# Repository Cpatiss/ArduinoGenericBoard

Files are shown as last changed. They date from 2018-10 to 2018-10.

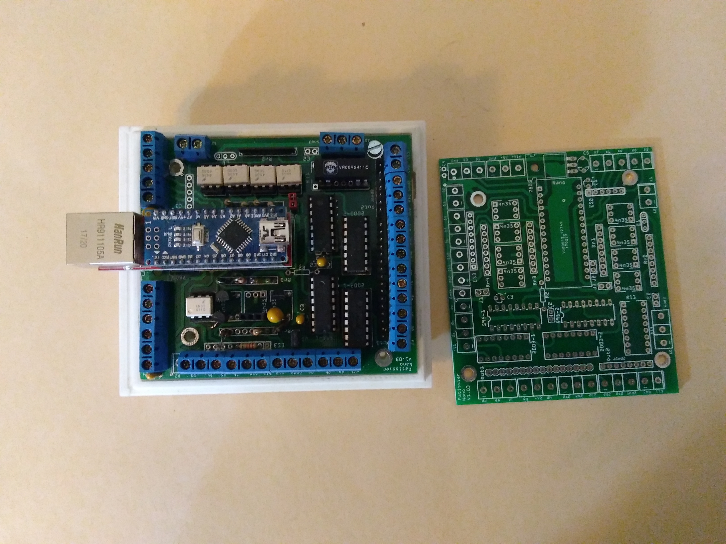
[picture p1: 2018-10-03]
IMG_20181002_145330114.jpg

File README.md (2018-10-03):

# ArduinoGenericBoard
Generic board for Arduino Nano and ENC28J60 Shield (optional)

PCB layout, fritzing included, gerber files in zip also included for Arduino Nano with printer 3D Case
Case is able to set on DIN rail
+ With optional shield RJ45 ENC28J60 - drive by UIPEthernet.h via SPI 10-11-12-13 pins. 
+ With 2 shift registers (SN74HC595) and 2 drivers (ULN 2003) witch provide 16 extra OUTs (14 drived by ULN provide high current outputs, one connected to reed relay) (only use D7, D8, D9 for synchrone serial)
+ With 7 optocouplers 4N25 or equ. (6 for input ,1 for output).All pul-up resistors could be individual or resistor type B array
+ With Voltage regulator (7805).It can be added a cooling radiator (on the bottom side if shield ENC28J60 plugs as picture show)

All the input/output are on screw terminal (protected by case) arround the case and both (almost) on a 2.54 SIL connector.

A sample of arduino program (to be continued) is also included.

Boitier (sur rail DIN) pour une carte arduino Nano (Tracé de circuit Frtizing inclus, fichiers  des gerber en zip aussi) incluant :
+ La place pour une carte ENC28J60 shield internet pour Nano (utilisant la liaison SPI via les E/S D10,11,12 et 13).
Cette carte est optionnelle ces E/S sont sinon disponibles sur les borniers.
+ 2 registres à décalage (SN74HC595) accolés à deux drivers (ULN2003) procurant 14 sorties fort courant plus une connectée à un relais reed.
Ces sorties n'utilisent que 3 E/S de l'arduino (D7,8 et9).
+ 6 Entrées optocouplées et une sortie optocouplée via des 4N25 (ou équivalents). Toutes les résistances de tirages peuvent être individuelles ou des réseaux de resistances de type B.
+ Un régulateur de tension (7805) avec radiateur (celui-ci doit être monté coté soudure en cas d'utilisation du shield internet , comme sur les photos jointes).

Toutes les entrées/ sorties sont disponibles sur des bornes à vis (d'accès protégé par le boitier) disposées tout autour de celui-ci et pour la plupart disponibles sur des connecteurs SIL au pas de 2.54.

Un petit exemple de programme arduino (à compléter) est également disponible.

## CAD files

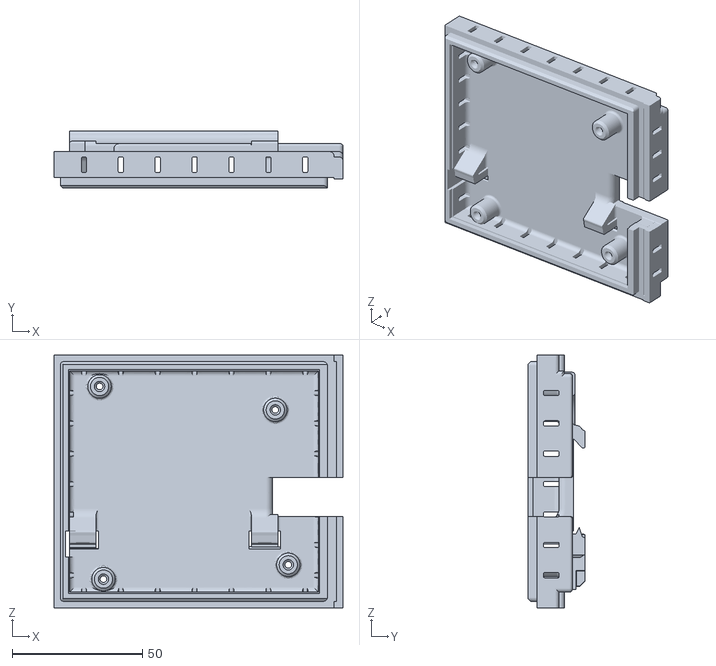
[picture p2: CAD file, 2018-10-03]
Down din V30.stl
111.0 x 22.0 x 97.0

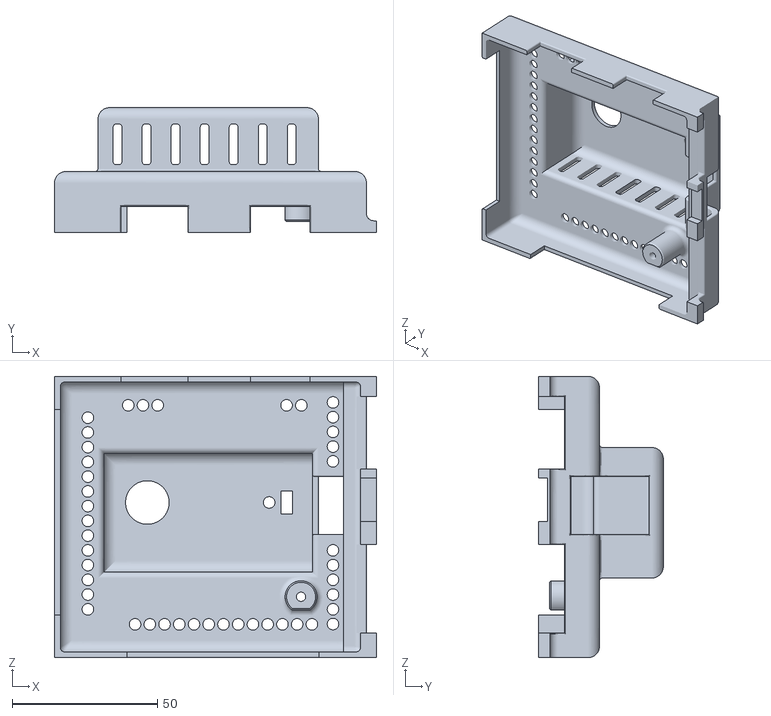
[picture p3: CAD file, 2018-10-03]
Top V22.stl
111.0 x 43.0 x 97.0

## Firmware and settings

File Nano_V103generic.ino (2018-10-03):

#define withinternet "yes" // commenté ou décommenté pour utilisation du shield ENC28J60/ comment or uncomment for use or not ENC28J60 Shield
#ifdef withinternet 
	#include <UIPEthernet.h>
	#include <SPI.h>
#else
	//#include <UIPEthernet.h> // certains compilateur reclame cette ligne / somme compiltor nedd this line
#endif

#define indebugmode "yes" // mode débuguage / mode debug

#define uchar unsigned char // pour faciliter code / for easier code
#define uint  unsigned int // pour faciliter code / for easier code

/* base sur le circuit imprime Nano V1.03 fritzing avec un arduino nano 
based on nano v1.03 Board see fritzing project with arduino nano chip  */

/* utilisation de deux '74HC595' (registre a decalage 8 bits) montes en serie pour generer 16 sorties (14 driver par dalington ULN2003) avec 3 pins seulement
	to drive 16 outputs (14 drive through darlington, ULN2003) via two 74HC595 (shift register) with only 3 pins */
#define pin_Ser  9   //pin 14 (ser) on the 75HC595 n° 1 data serial
#define pin_RClk  8  //pin 12 on the 75HC595 (RCLK) = data set
#define pin_SrClk  7 //pin 11 on the 75HC595 (SRCLK) = Data shift

uchar FirstOutputValue = '\0'; // valeurs des 8 premieres sorties (74hc595 n°1) / value of the first 74hc595 8 first outputs
uchar SecondOutputValue = '\0'; // valeurs des 8 dernieres sorties (74hc595 n°2) / value of the second 74hc595 8 lest outputs values

#ifdef withinternet 
  #define pin_I13_Sck 13 // pin D13 entree  optocouple (sck) vers moduel ethernet / D13 input sck for shield internet
  #define pin_I12_Miso 12 // pin D12 en entree optocouple  (miso) vers module ethernet / D12 input miso for shield internet
  #define pin_O11_Mosi 11 // pin D11 en sortie optocouple (mosi) vers module ethernet / D11 output mosi for shield internet
  #define pin_O10_Css 10 // pin D10 en sortie module ethernet (css) vers module ethernet / D13 output css for shield internet
#endif
#define pin_I06 6 // pin D6 en entree optocouple (rx manchester filaire ou rf)
#define pin_O05 5 // pin D5 en Sorties directe (out RF ou filaire manchester)
#define pin_IO04 4 // pin D4 en E/S directe
#define pin_IO03 3 // pin D3 en E/S directe
#define pin_IO02 2 // pin D2 en E/S directe

#define pin_IO01 1 // pin D1 tx/rx serial use with usb/serial link not use on board nano v1.03
#define pin_IO00 0 // pin D0 tx/rx serial use with usb/serial link not use on board nano V1.03

#define pin_IA0 A0 // pin A0 en entree optocouple (...)
#define pin_IA1 A1 // pin A1 en entree optocouple (...)
#define pin_IA2 A2 // pin A2 en entree optocouple (...)
#define pin_IOA3 A3 // pin A3 en entree sortie directe (...)
#define pin_IOA4 A4 // pin A4 en entree sortie directe (...)
#define pin_IOA5 A5 // pin A5 en sortie directe (...)
#define pin_IOA6 A6 // pin A6 en entree sortie directe (...)
#define pin_IOA7 A7 // pin A7 en entree sortie directe (...)

//def & init for machester
#define BUFFER_SIZE 4 // 3*8 bits = 24 bits (ou 32 bits passer alors  4)  habituel de manchester code chacon (voir pour diagral) par exemple, changer selon besoin
// when use manchester number of bytes used (3 for 24bits long message , 4 for 32 ..) change depend on define bellow
// Modifier aussi le traitement des codes recus dans LOOP // Change also recieve sub in loop function

uint8_t buffer[BUFFER_SIZE + 1];
#ifdef indebugmode
	// int serialNumModule = 0; // numero du module pour les envois serial (/0 ,/1,/2,/3,/4...)
#endif


#ifdef withinternet
	// L'adresse MAC du shield // mac adress of shield
	byte mac[] = { 0x90, 0xA2, 0xDA, 0x0E, 0xA5, 0x7D };
	// L'adresse IP que prendra le shield // fixed ip 
	IPAddress ip(10, 10, 1, 85);

	// Initialise notre serveur / initialize server
	// Ce dernier ecoutera sur le port 80 / server listen on port 80
	EthernetServer serveur(80);

	String url = String("") ; // L'url recu a stocker / to store url received from client
	//char url[100];
	char index = 0; // index indiquant ou l'on est rendu dans la chaine / index of current character of url
#endif


void setup()
{

  // pins 
  #ifdef withinternet 
	  pinMode(pin_I13_Sck, INPUT); // e/s horloge spi web / input/out clock shield web
	  pinMode(pin_I12_Miso , INPUT); // entrée miso spi web / input miso shield web
  #else
    pinMode(pin_I13_Sck, INPUT); // entrée optocouplée / optocoupled input
    pinMode(pin_I12_Miso , INPUT); // entrée optocouplée / optocoupled input
  #endif
	pinMode(pin_I06, INPUT); // input rx (rf ou filaire) manchester
	pinMode(pin_IA0, INPUT);
	pinMode(pin_IA1, INPUT);
	pinMode(pin_IA2, INPUT);
	
  #ifdef withinternet 
	  pinMode(pin_O11_Mosi, OUTPUT); // sortie mosi spi web  / out mosi shield web
	  pinMode(pin_O10_Css, INPUT);// E/sortie chip select shield web / out Css shield web
  #else
    pinMode(pin_O11_Mosi, OUTPUT); // sortie optocouplé  / optocoupled out 
    pinMode(pin_O10_Css, INPUT);// Entrée optocouplée / optocoupled input
  #endif
	pinMode(pin_O05, OUTPUT); // E/S directe / in/out direct
  
	pinMode(pin_Ser, OUTPUT); // ligne data série synchrone registre à décalage / data serial syncrone for shift registers
  pinMode(pin_RClk, OUTPUT); // ligne stockage série synchrone registre à décalage / lacth serial syncrone for shift registers
	pinMode(pin_SrClk, OUTPUT); // ligne horloge série synchrone registre à décalage / clock serial syncrone for shift registers
	
	//pinMode(LED_BUILTIN, OUTPUT);// to test

	// init
	SetOutput495(); // initialise a 0 les sorties des registres 74595 / reset all shift register output

#ifdef indebugmode
	Serial.begin(9600);
#endif
	
	char erreur = 0;
#ifdef withinternet
	// On demarre le shield Ethernet SANS adresse ip (donc donnee via DHCP) // try to start ethernet in DHCP
	//erreur = Ethernet.begin(mac); // décommenté pour démarrer en dhcp /uncomment to start in dhcp
  // ip fixe obligatoire pour le système domotic
	//if (erreur == 0) {// décommenté pour démarrer en dhcp /uncomment to start in dhcp
		#ifdef indebugmode
				Serial.println("IP F");
		#endif
		// si une erreur a eu lieu cela signifie que l'attribution DHCP
		// ne fonctionne pas. On initialise donc en forcant une IP
		Ethernet.begin(mac, ip);
	//}// décommenté pour démarrer en dhcp /uncomment to start in dhcp
	#ifdef indebugmode
		Serial.println("I..");
		Serial.println(Ethernet.localIP());
	#endif
	// Donne une seconde au shield pour s'initialiser
	delay(1000);
	// On lance le serveur
	serveur.begin();
	#ifdef indebugmode
		Serial.println("P!");
	#endif
#endif

	

}// fin setup / end setup 

void loop()
{
	/* set here your loop code
   *  poser ici votre code programme
	 */
#ifdef withinternet
	// traite les requetes web / Web server listen
	// Regarde si un client est connecte et attend une reponse/ look if client connected
	EthernetClient client = serveur.available();
	
	if (client) { // Un client est la ? / a client is here ?
		#ifdef indebugmode
			Serial.println("i!");
		#endif
		url = String("                     "); // on remet a zero notre chaine tampon /  reset string
		index = 0;
		while (client.connected()) { // Tant que le client est connecte / while client connected
			if (client.available()) { // A-t-il des choses a dire ? / and client have someting to say
				
				// traitement des infos du client / operate client string
				char carlu = client.read(); //on lit ce qu'il raconte / read string
				if (carlu != '\n') { // On est en fin de chaine ? / end of client string
					// non ! alors on stocke le caractere / no we continue
					#ifdef indebugmode
						Serial.print(carlu);
					#endif
					url[index] = carlu;
					index++;
					if (index > 25){ index = 0; Serial.println(""); }
				}
				else {
					// on a fini de lire ce qui nous interesse / end of client string
					#ifdef indebugmode
						Serial.println("");
					#endif
					// on marque la fin de l'url (caractere de fin de chaine) / set end of string by chr 0
					url[index] = '\0';
					boolean ok = WebValid(client); // essaie d'interpreter la chaine / try to explot string
					if (ok) {
						// tout s'est bien passe = on met a jour les broches / if all is ok operate
           /* poser ici votre code de fin de traitement web 
            *  set here your end web treatment code 
            */
						//ction();
					}
					break;
				}
			}
		}
		// Donne le temps au client de prendre les donnees / left time client to recieve answer
		delay(10);
		// Ferme la connexion avec le client / close client connection
		client.stop();
		#ifdef indebugmode
				Serial.println("o!");
		#endif
	}
#endif

} // fin loop / end loop

#ifdef withinternet
	 boolean WebValid(EthernetClient client) {
		// renvoi true si la chaine est valide, traite les infos de la chaine
		//Serial.print("receive : ");
		//	Serial.print(url);
		int pos = url.indexOf("o="); // si message commence par o= alors met sorties à jour/ if message begin by 'o=' set output as sended
		//Serial.println(pos);
		if (pos > 0) {
			// renvoi ok 
			enteteClientWebJson(client);
			client.println("OK");
			//puis traite message
			Set3FristBuffer(pos);
			if (buffer[1] != 1) {
				// ordre <>1 met les sorties demandés dans le message / order <>1  set output as value sended 
				char tmp[2] = {'0', url[pos + 9]};
        int numModuleCourant = 0;
				numModuleCourant = atoi(tmp);
				// Serial.println(numModuleCourant);
				FirstOutputValue = (FirstOutputValue | 0x7F) & ( numModuleCourant);
				SetOutput495();
			
			}
			else {
				// ordre de modifier les sorties du nano
				if (( buffer[2] & 0x01 )==1) { 
				SecondOutputValue = buffer[2]>>1;
				SetOutput495();
				}
       
			}
			
			return true;
		}
		else // si le message ne commnce pas par 'o=' / if message not begin by 'o='
      // envoi la page Web des statuts des entrées et sorties / send web page with input/output status
			{
				pos = url.indexOf("S=");
				//Serial.println(pos);
				if (pos > 0) {
					Set3FristBuffer(pos);
					// puis message traite
					enteteClientWebJson(client);
					client.print("{\"ST\":");
					// client.print(lastHeaderGroup); // libre pour une donnée à envoyer de votre programme / free for a data to send of your own program
					client.print(",");
					//client.print(lastHeaderModule); // libre pour une donnée à envoyer de votre programme / free for a data to send of your own program
         /* // libre pour des données à envoyer de votre programme / free for multi datas to send of your own program
					for (int j = 0; j < NbType; j++) {
						client.print(",");
						client.print(statutModule[j]);
					}
					for (int j = 0; j < NbModule; j++) {
						client.print(",");
						client.print(positionModule[j]);
					}
         */
					client.print(",");
					client.print(digitalRead(A3) * 64 + digitalRead(A2) * 32 + digitalRead(A1) * 16 + digitalRead(A0) * 8 + digitalRead(4) * 4 + digitalRead(3) * 2 + digitalRead(2));
					for (int j = A0; j <= A7; j++) {
						client.print(",");
						client.print(analogRead(j));
					}
					client.print(",");
					client.print(FirstOutputValue);
					client.print(",");
					client.print(SecondOutputValue);
          
					client.println("}");
					return true;
				}
				else {
				// puis message traite
				enteteClientWebJson(client);
				client.println("ERR No Order");
				#ifdef indebugmode
					Serial.println("no tra");
				#endif
				return false;
				}
			
			}
		} //  find WebValide / end web valid
#endif
#ifdef withinternet
	 void Set3FristBuffer(int pos) {
		 // met les trois premières valeurs à partir de pos de l'url dans les buffers 1 et 2 avec 0 = 4 / treat 3 first characters of string in char array
		 buffer[0] = 4;
		 char ord[3] = { url[pos + 2], url[pos + 3], url[pos + 4] };
		 buffer[1] = atoi(ord);
		 ord[0] = url[pos + 5];
		 ord[1] = url[pos + 6];
		 ord[2] = url[pos + 7];
		 buffer[2] = atoi(ord);
	 }
	void enteteClientWebJson(EthernetClient client) {
		// envoi l'entete de reponse pour le client web en json / set headtext of jason message
		// Tout d'abord le code de reponse 200 = reussite
		client.println("HTTP/1.1 200 OK");
		// Puis le type mime du contenu renvoye, du json
		client.println("Content-Type: application/json");
		// Autorise le cross origin
		client.println("Access-Control-Allow-Origin: *");
		// Et c'est tout !
		// On envoi une ligne vide pour signaler la fin du header
		client.println();
	}
#endif
void SetOutput495()
{
	/* envoi les valeurs des sorties n°1  et 2 sur les 74Hc595 en effectuant des decalages a gauche
	send serial datas to two 74hc595 via shift integer*/
		

	/* lacth pin a la masse / ground latchPin and hold low for as long as you are transmitting */
	digitalWrite(pin_RClk, LOW);
	// envoi les deux bytes par decalage /send two datas bytes by shift //
	shiftOut(pin_Ser, pin_SrClk, MSBFIRST, SecondOutputValue);
	shiftOut(pin_Ser, pin_SrClk, MSBFIRST, FirstOutputValue);
   //Serial.println(FirstOutputValue);
  //Serial.println(SecondOutputValue);
	//lacth pin a +5 v / return the latch pin high to signal chip that it 
	//no longer needs to listen for information
	digitalWrite(pin_RClk, HIGH);
	// retour a l'etat initial de latch pin
	digitalWrite(pin_RClk, LOW);
}
